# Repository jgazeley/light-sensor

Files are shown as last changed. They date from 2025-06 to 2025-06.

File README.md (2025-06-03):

# light-sensor

**Wheatstone-bridge LDR -> LM358 op-amp -> ADC0804 -> SN74LS283/SN74LS86 8-bit adder/subtractor**  
Manual B-input via DIP switches, Add/Subtract mode, producing a 0–5 V (0–255) digital result with carry flag.

---


---

## Overview

- **Light to Voltage (Input A):**  
  - LDR in a Wheatstone bridge (along with three 22 kΩ resistors).  
  - **LM358** buffers and scales the bridge output so **0 V = dark** and **5 V = bright**.  
  - A **10 kΩ trim pot** plus an optional **100 Ω “pull-down”** ensures exact 0 V floor and 5 V ceiling.  

- **Analog to Digital:**  
  - **ADC0804** (8-bit) reads the LM358 analog output (0–5 V) and outputs an 8-bit value (0…255).  
  - Three 100 pF capacitors (150 pF total) and a 10k resistor set the ADC clock.  
    _See typical applications on page 11 of [ADC0804 datasheet](https://www.ti.com/lit/ds/symlink/adc0804-n.pdf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) (“Self-Clocking in Free-Running Mode”)._  

- **Input B:**  
  - Eight SPDT DIP switches let you choose any number between 0 and 255.  
  - A Mode switch flips between **Add** and **Subtract**.  

- **Adder/Subtractor Logic:**  
  - Two **SN74LS283N** (4-bit full adders) combined for 8 bits.  
  - Two **SN74LS86AN** (quad XOR gates) invert B-bits when subtracting and feed the initial carry-in.  
  - A Carry/Borrow LED indicates overflow (addition) or borrow (subtraction).  

- **Output Display:**  
  - One 10-segment LED bar-graph (only 8 segments used) shows bits 7…0 (MSB on the left).  
  - Carry/Borrow LED shows if there’s overflow/borrow.  

- **Power:**  
  - Board requires **9 V** (for the bridge + LM358) and **5 V** (for ADC + logic + LEDs).  
  - I used two small adjustable buck converters: one set to 9 V, the other set to 5 V (both fed from a 12 V source).  

---

## Parts

### ICs
- **2 × SN74LS283N** — 4-bit Binary Full Adder (16-DIP)  
  [SN74LS283N datasheet (TI)](https://www.ti.com/lit/ds/symlink/sn74ls283.pdf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)  
- **2 × SN74LS86AN** — Quad 2-Input XOR Gate (14-DIP)  
  [SN74LS86AN datasheet](https://mm.digikey.com/Volume0/opasdata/d220001/medias/docus/2380/SN54%2C74%28LS%2CS%2986%28A%29.pdf)  
- **1 × ADC0804LCWM/NOPB** — 8-bit Analog-to-Digital Converter (20-SOIC)  
  [ADC0804 datasheet (TI)](https://www.ti.com/lit/ds/symlink/adc0804-n.pdf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)  
- **1 × LM358N/NOPB** — Dual General-Purpose Op Amp (8-DIP)  
  [LM158/LM358 datasheet (TI)](https://www.ti.com/lit/ds/symlink/lm158-n.pdf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)

### Resistors & Pots
- **3 × 22 kΩ** (Wheatstone bridge)  
- **1 × 10 kΩ pot** (LM358 feedback adjustment, to pinpoint 5V high)  
- **1 × 100 Ω** pull-down on LM358 output (hacky shit to force < 10 mV output)  
- **4 × 100 kΩ & 2 × 10 kΩ** (op-amp inputs, feedback, ADC clock)  
- **~26 × 330 Ω** (LED current-limiting resistors)

### Capacitors
- **3 × 100 pF** (ADC clock timing; combined = 150 pF)  
- **2 × 1 µF / 50 V** electrolytic (9 V & 5 V rails)

### Switches & LEDs
- **1 × 8-way SPDT DIP switch** (B-input bits)  
  _Example: [MCTIIR-08-T](https://www.newark.com/multicomp-pro/mctiir-08-t/switch-dip-8-position-spst-recessed/dp/74M3077)_
- **1 × SPDT toggle** (Add/Subtract mode)  
  _Example: [SLW-1276864-4A-D](https://www.digikey.com/en/products/detail/same-sky-formerly-cui-devices/SLW-1276864-4A-D/21259972)_
- **1 × Momentary pushbutton** (ADC reset)  
- **1 × LDR** (~22 Ω bright, ~20 kΩ dark)  
- **2 × Single LEDs** (Analog-Mid (ADC bit 7) + Carry/Borrow)  
- **3 × 10-LED bar-graph modules** (only 8 LEDs used per graph)  
  _Example: [Adafruit 10-Segment Light Bar Graph](https://www.adafruit.com/search?q=10%20Segment%20Light%20Bar%20Graph)_

### Power Modules
- **2 × Buck converter (adjustable)**  
  _Example: [eBoot MP1584EN DC-DC Buck Converter Kit (Amazon)](https://www.amazon.com/dp/B07RVG34WR)_  

---

## PCB & Documentation

- **KiCad 3D Render:**  
  KiCad 3D Render  
  *Figure: PCB 3D render in KiCad.*

- **KiCad PCB Screenshot:**  
  KiCad PCB View  
  *Figure: PCB layout in KiCad.*

- **CircuitMaker Schematic (Low Output):**  
  CircuitMaker Low Output  
  *Figure: CircuitMaker schematic showing low output (~0 V).*

- **CircuitMaker Schematic (High Output):**  
  CircuitMaker High Output  
  *Figure: CircuitMaker schematic showing high output (5 V when LDR is ~22 Ω).*

- **Development:** 
  Development Board (Removable ICs)  
*Figure: Development board with removable IC sockets.*

  Breadboard example  
*Figure: Working example on breadboards.*

- **Soldered ICs:**  
  Final Board  
  *Figure: Partially assembled board with ICs soldered directly.*

---

## Usage Notes

1. **Calibrating the LM358:**  
   - If the LM358 cannot swing fully to 0 V, install the **100 Ω pull-down** on its output.  
   - In bright light, adjust the **10 kΩ feedback pot** until LM358 output = 5.000 V exactly.  

2. **Verifying the ADC0804:**  
   - With LM358 output = 0 V, ADC should output all zeros.  
   - With LM358 output = 5 V, ADC should output decimal 255 (all ones).  

3. **Adder/Subtractor Testing:**  
   - Set **B = 0** (all DIP switches OFF), **MODE = Add**: the bar graph should match the ADC reading (0…255).  
   - Set **B** to a known pattern (e.g., 00001111 = 15), **MODE = Add**: output = A + 15 (watch for carry LED).  
   - Switch to **Subtract** (MODE = 1): output = A – B (two’s complement). If A < B, the Borrow LED lights; the bar graph shows (A – B mod 256).  

4. **Power Port Pinout (5-pin header, top to bottom)**  
   1. **9V** – Powers Wheatstone bridge & LM358  
   2. **5V** – Powers ADC0804, SN74LS logic, and LEDs  
   3. **NC** – No Connection  
   4. **NC** – No Connection  
   5. **GND** – Ground reference for both 9V and 5V rails  

---

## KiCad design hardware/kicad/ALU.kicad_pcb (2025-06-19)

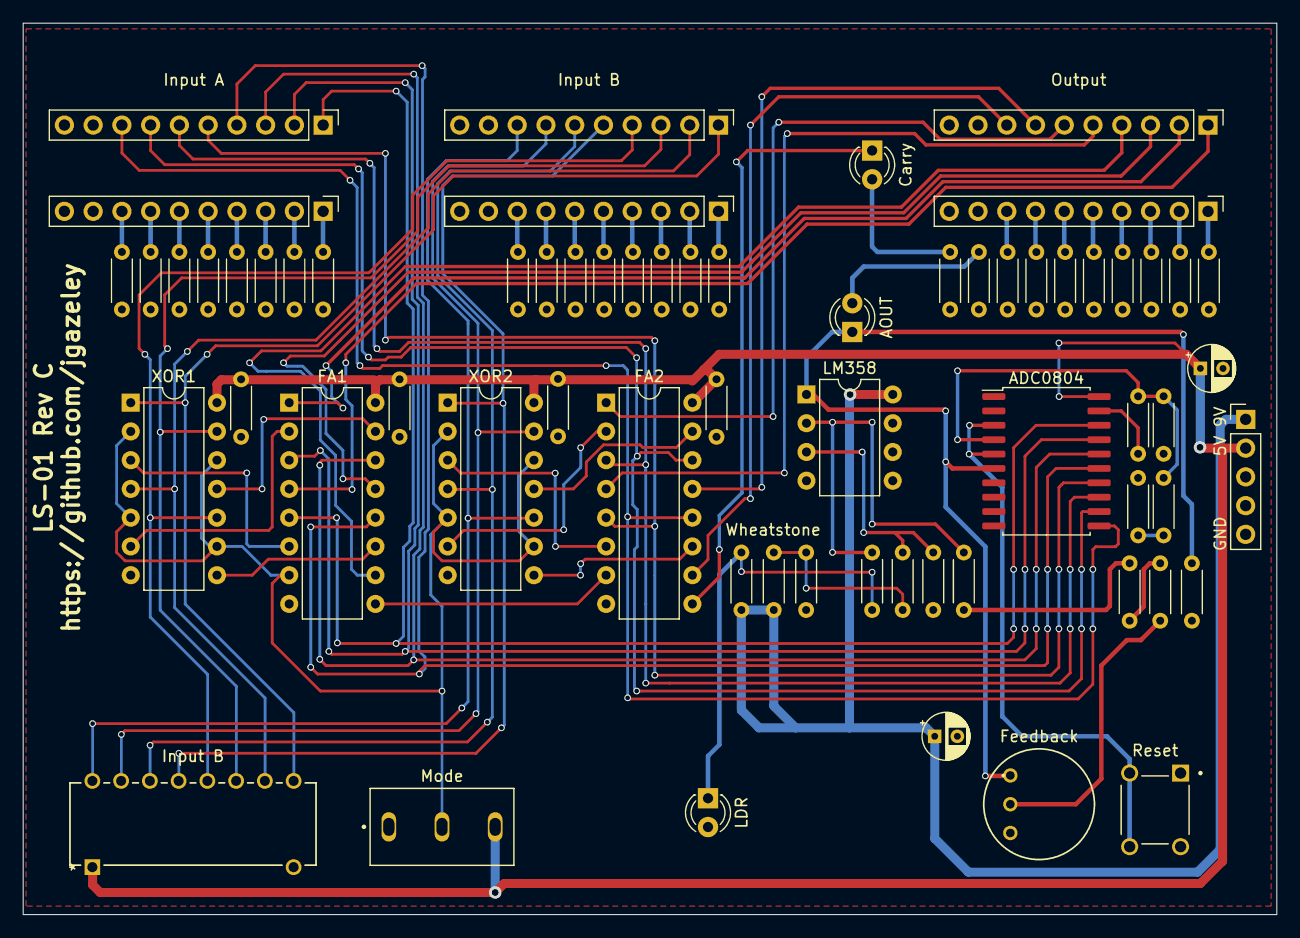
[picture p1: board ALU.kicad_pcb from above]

Board: 2 copper layers, 110.8 x 78.8 mm, 18 parts (0 on the bottom side), 41 nets.

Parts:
ADC0804: SOIC-20W_7.5x12.8mm_P1.27mm
AOUT: LED_D3.0mm
Carry: LED_D3.0mm
FA1, FA2: DIP-16_W7.62mm
Feedback: RES3_91A_TTE
GND       5V 9V: PinHeader_1x05_P2.54mm_Vertical
Input A: PinHeader_1x10_P2.54mm_Vertical
Input B: PinHeader_1x10_P2.54mm_Vertical
Input B#2: MCTIIR-08-T_MTC
LDR: LED_D3.0mm
LM358: DIP-8_W7.62mm
Mode: SW_SLW-1276864-4A-D
Output: PinHeader_1x10_P2.54mm_Vertical
Reset: SW_TS02-66-70-BK-100-LCR-D
Wheatstone: R_Axial_DIN0204_L3.6mm_D1.6mm_P5.08mm_Horizontal
XOR1, XOR2: DIP-14_W7.62mm

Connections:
5V: ADC0804.20, FA1.16, FA2.16, GND 5V 9V.2, Input B#2.1, Mode.3, XOR1.14, XOR2.14
9V: GND 5V 9V.1, LM358.8, Wheatstone.1
A1: ADC0804.18, FA1.5, Input A.1
A2: ADC0804.17, FA1.3, Input A.2
A3: ADC0804.16, FA1.14, Input A.3
A4: ADC0804.15, FA1.12, Input A.4
A5: ADC0804.14, FA2.5, Input A.5
A6: ADC0804.13, FA2.3, Input A.6
A7: ADC0804.12, FA2.14, Input A.7
A8: ADC0804.11, FA2.12, Input A.8
AOUT: ADC0804.6, AOUT.1, Feedback.1, LM358.1
B1: Input B.1, Input B#2.9, XOR1.1
B2: Input B.2, Input B#2.10, XOR1.4
B3: Input B.3, Input B#2.11, XOR1.13
B4: Input B.4, Input B#2.12, XOR1.10
B5: Input B.5, Input B#2.13, XOR2.1
B6: Input B.6, Input B#2.14, XOR2.4
B7: Input B.7, Input B#2.15, XOR2.13
B8: Input B.8, Input B#2.16, XOR2.10
B'1: FA1.6, XOR1.3
B'2: FA1.2, XOR1.6
B'3: FA1.15, XOR1.11
B'4: FA1.11, XOR1.8
B'5: FA2.6, XOR2.3
B'6: FA2.2, XOR2.6
B'7: FA2.15, XOR2.11
B'8: FA2.11, XOR2.8
C4: FA1.9, FA2.7
GND: ADC0804.1, ADC0804.2, ADC0804.7, ADC0804.8, ADC0804.10, FA1.8, FA2.8, GND 5V 9V.5, Input B#2.8, LDR.2, LM358.4, Mode.1, Reset.1, Reset.2, XOR1.7, XOR2.7
LDR: LDR.1, Wheatstone.2
MODE: FA1.7, Mode.2, XOR1.2, XOR1.5, XOR1.9, XOR1.12, XOR2.2, XOR2.5, XOR2.9, XOR2.12
Overflow: Carry.1, FA2.9
Reset: ADC0804.3, ADC0804.5, Reset.3, Reset.4
S1: FA1.4, Output.1
S2: FA1.1, Output.2
S3: FA1.13, Output.3
S4: FA1.10, Output.4
S5: FA2.4, Output.5
S6: FA2.1, Output.6
S7: FA2.13, Output.7
S8: FA2.10, Output.8

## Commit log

2025-06-03 PCB stuff
    [ALU.kicad_pcb]
2025-06-19 Refactor project structure
    [ALU.kicad_pcb]
2025-06-19 Add gerber.zip
